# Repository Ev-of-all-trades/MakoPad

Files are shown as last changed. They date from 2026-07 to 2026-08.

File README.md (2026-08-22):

# MakoPad
This is a 6 key macropad that I designed in KiCad and is programmed with QMK. It features a 1.8" LCD display, 6 hot-swappable keys, a rotary encoder, and 2 buttons to switch the layers. This Project has been made specially for programmers on FRC 5199 Robot Dolphins From Outer Space to help them with FRC Programming. 

PCB and Schematic
-----------------------------------------------------



Below is A picture of the assembly I made in Fusion 360.
------------------------------------------------------------------------------------
PCB Assembly [mind the crappy display model, i couldn't find a better one since there wasn't any for the specific one i wanted to use]


Here is the plan for developing the programming
--------------------------------------------------
Phase 1: Keyboard matrix
- Program the keyboard matrix and build the layers
- Test matrix to make sure it works

Phase 2: Rotary encoder
- Add the rotary encoder and rotary encoder switch into the programming
- Program the special functions for the rotary encoder
  - Make it so that whenever the rotary encoder is pressed down, you can rotate the knob to select what function you want to rotary encoder to do
- Test rotation and clicking

Phase 3: Layer buttons
- Program the button to change the keyboard matrix layers
  - The top button switches to the next layer and the bottom one switches to the previous layer

Phase 4: The display
- Make the display interface with the microcontroller

Phase 5: Make it awesome
- Layer-dependent key labels
- Encoder modes
- Custom macros
- Startup screen
- MakoPad logo
- Current layer display
- Key function display

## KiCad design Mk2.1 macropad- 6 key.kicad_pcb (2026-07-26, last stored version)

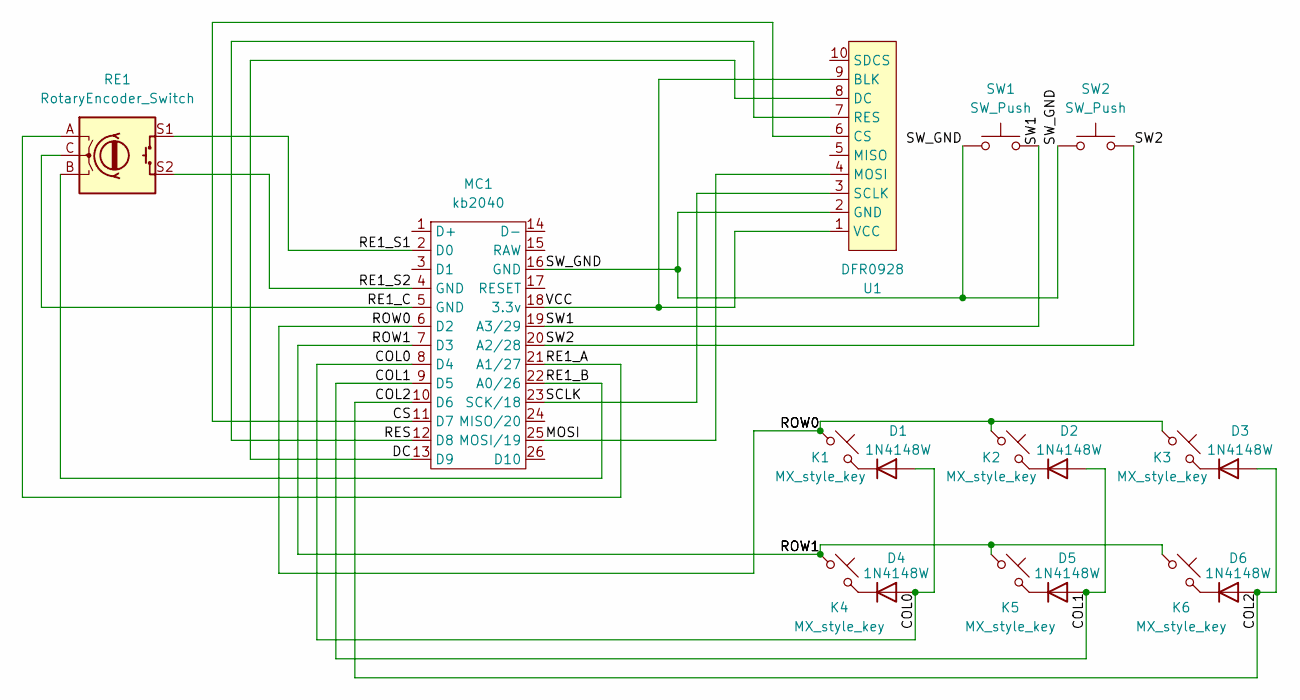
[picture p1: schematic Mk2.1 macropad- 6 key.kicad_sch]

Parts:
D1, D2, D3, D4, D5, D6: 1N4148W; D_SOD-123
K1, K2, K3, K4, K5, K6: MX_style_key; Kailh MX hot-swap socket [part #PG151101S11]
MC1: kb2040
RE1: RotaryEncoder_Switch; RotaryEncoder_Alps_EC11E-Switch_Vertical_H20mm
SW1, SW2: SW_Push; SW_PUSH-12mm
U1: DFR0928; Fermion 1.8in 128x160 IPS TFT LCD Display

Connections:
/COL0: D1.2 (A), D4.2 (A), MC1.8 (D4)
/COL1: D2.2 (A), D5.2 (A), MC1.9 (D5)
/COL2: D3.2 (A), D6.2 (A), MC1.10 (D6)
/CS: MC1.11 (D7), U1.6 (CS)
/DC: MC1.13 (D9), U1.8 (DC)
/MOSI: MC1.25 (MOSI/19), U1.4 (MOSI)
/RE1_A: MC1.21 (A1/27), RE1.A
/RE1_B: MC1.22 (A0/26), RE1.B
/RE1_C: MC1.5 (GND), RE1.C
/RE1_S1: MC1.2 (D0), RE1.S1
/RE1_S2: MC1.4 (GND), RE1.S2
/RES: MC1.12 (D8), U1.7 (RES)
/ROW0: K1.1, K2.1, K3.1, MC1.6 (D2)
/ROW1: K4.1, K5.1, K6.1, MC1.7 (D3)
/SCLK: MC1.23 (SCK/18), U1.3 (SCLK)
/SW1: MC1.19 (A3/29), SW1.2
/SW2: MC1.20 (A2/28), SW2.2
/SW_GND: MC1.16 (GND), SW1.1, SW2.1, U1.2 (GND)
/VCC: MC1.18 (3.3v), U1.1 (VCC), U1.9 (BLK)
unnamed: D1.1 (K), K1.2
unnamed: D2.1 (K), K2.2
unnamed: D3.1 (K), K3.2
unnamed: D4.1 (K), K4.2
unnamed: D5.1 (K), K5.2
unnamed: D6.1 (K), K6.2

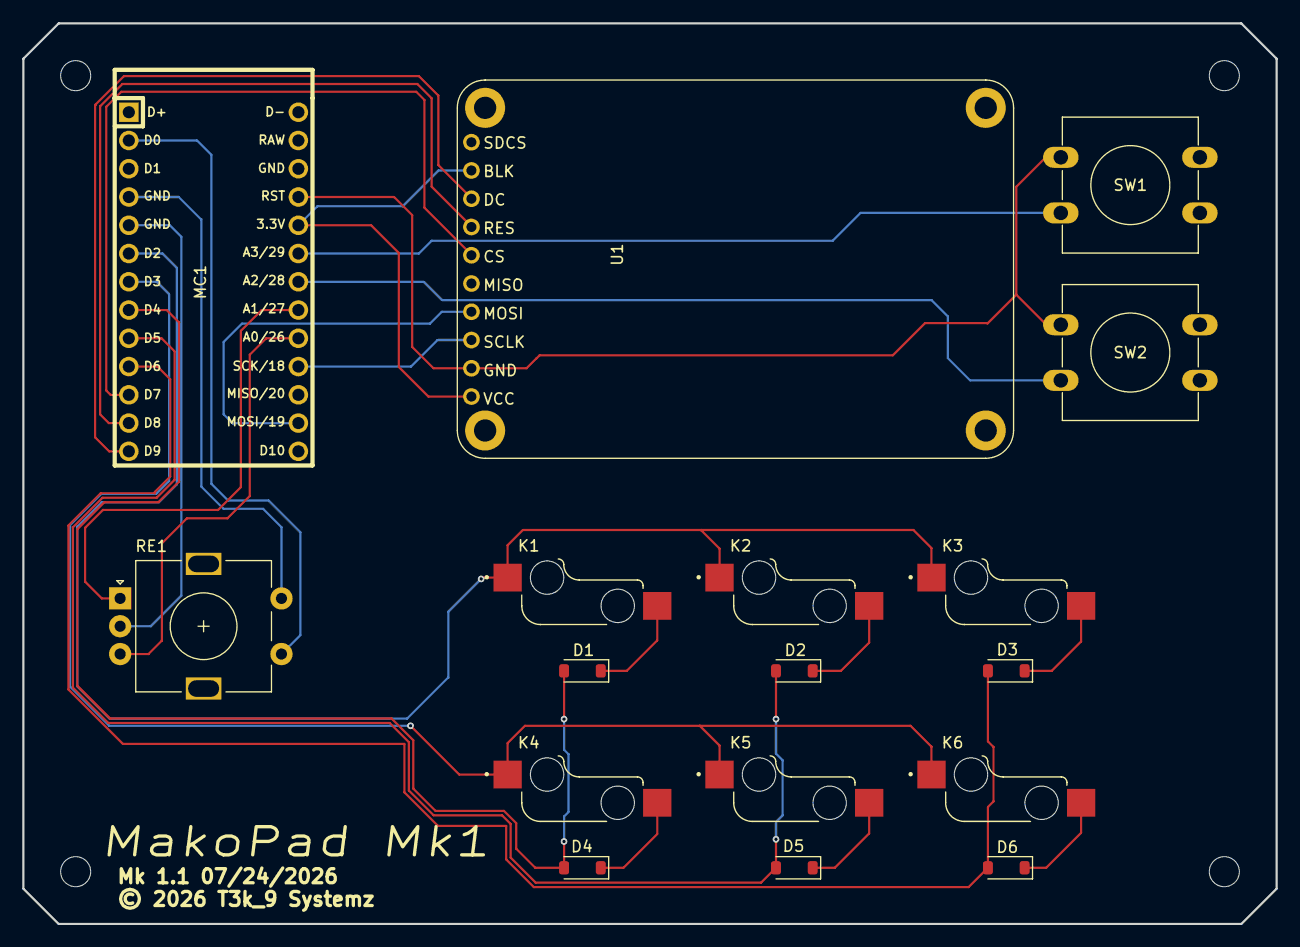
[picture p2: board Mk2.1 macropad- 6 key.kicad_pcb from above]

Board: 2 copper layers, 112.7 x 80.9 mm, 17 parts (0 on the bottom side), 25 nets.

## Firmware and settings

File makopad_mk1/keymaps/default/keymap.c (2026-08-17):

#include QMK_KEYBOARD_H

// ENCODER MODES
typedef enum {
    ENC_VOLUME,
    ENC_SCROLL,
    ENC_BRIGHTNESS
} encoder_mode_t;

static encoder_mode_t encoder_mode = ENC_VOLUME;


// =============================================================================
// LAYERS
// =============================================================================

enum layers {
    _BASE,
    _FRC,
    _DS,
    _LIMELITE,
    _LAYER_COUNT
};


// =============================================================================
// CUSTOM KEYCODES
// =============================================================================

enum custom_keycodes {

    // FRC / VS Code
    FRC_BUILD = SAFE_RANGE,
    FRC_DEPLOY,
    FRC_SIMULATE,
    FRC_DEBUG,
    FRC_RIOLOG,
    FRC_SHUFFLEBOARD,

    // Driver Station
    DS_ENABLE,
    DS_DISABLE,
    DS_TELEOP,
    DS_AUTO,
    DS_TEST,
    DS_ESTOP,
    DS_ASTOP,
    DS_REFRESH,

    // Limelight
    LIMELIGHT_LEFT,
    LIMELIGHT_FRONT,
    LIMELIGHT_RIGHT
};


// =============================================================================
// STANDALONE GPIO PINS
// =============================================================================

#define ENCODER_SW_PIN GP0
#define LAYER_NEXT_PIN GP28
#define LAYER_PREV_PIN GP29


// =============================================================================
// INITIALIZATION
// =============================================================================

void keyboard_post_init_user(void) {

    // Rotary encoder push switch
    setPinInputHigh(ENCODER_SW_PIN);

    // Layer buttons
    setPinInputHigh(LAYER_NEXT_PIN);
    setPinInputHigh(LAYER_PREV_PIN);
}


// =============================================================================
// KEYMAPS
// =============================================================================

const uint16_t PROGMEM keymaps[][MATRIX_ROWS][MATRIX_COLS] = {

    // -------------------------------------------------------------------------
    // BASE LAYER
    // -------------------------------------------------------------------------

    [_BASE] = LAYOUT_ortho_2x3(
        KC_A, KC_B, KC_C,
        KC_D, KC_E, KC_F
    ),


    // -------------------------------------------------------------------------
    // FRC PROGRAMMING
    // -------------------------------------------------------------------------

    [_FRC] = LAYOUT_ortho_2x3(
        FRC_BUILD,
        FRC_DEPLOY,
        FRC_SIMULATE,

        FRC_DEBUG,
        FRC_RIOLOG,
        FRC_SHUFFLEBOARD
    ),


    // -------------------------------------------------------------------------
    // DRIVER STATION
    // -------------------------------------------------------------------------

    [_DS] = LAYOUT_ortho_2x3(
        DS_ENABLE,
        DS_DISABLE,
        DS_TELEOP,

        DS_AUTO,
        DS_TEST,
        DS_ESTOP
    ),


    // -------------------------------------------------------------------------
    // LIMELITE
    // -------------------------------------------------------------------------

    [_LIMELITE] = LAYOUT_ortho_2x3(
        LIMELIGHT_LEFT,
        LIMELIGHT_FRONT,
        LIMELIGHT_RIGHT,

        KC_NO,
        KC_NO,
        KC_NO
    )
};


// =============================================================================
// CUSTOM KEYCODE PROCESSING
// =============================================================================

bool process_record_user(uint16_t keycode, keyrecord_t *record) {

    // Only execute macros when the key is pressed.
    if (!record->event.pressed) {
        return true;
    }

    switch (keycode) {

        // =====================================================================
        // FRC / VS CODE
        // =====================================================================

        case FRC_BUILD:

            // Ctrl + Alt + B
            tap_code16(LCTL(LALT(KC_B)));

            return false;


        case FRC_DEPLOY:

            // Ctrl + Alt + D
            tap_code16(LCTL(LALT(KC_D)));

            return false;


        case FRC_SIMULATE:

            // Ctrl + Alt + S
            tap_code16(LCTL(LALT(KC_S)));

            return false;


        case FRC_DEBUG:

            // Ctrl + Alt + G
            tap_code16(LCTL(LALT(KC_G)));

            return false;


        case FRC_RIOLOG:

            // Ctrl + Alt + R
            tap_code16(LCTL(LALT(KC_R)));

            return false;


        case FRC_SHUFFLEBOARD:

            // Ctrl + Alt + M
            tap_code16(LCTL(LALT(KC_M)));

            return false;


        // =====================================================================
        // DRIVER STATION
        // =====================================================================

        case DS_ENABLE:

            // Driver Station native enable shortcut:
            // [ + ] + \ 
            tap_code(KC_LBRC);
            tap_code(KC_RBRC);
            tap_code(KC_BSLS);

            return false;


        case DS_DISABLE:
            // Enter
            tap_code(KC_ENT);

            return false;


        case DS_TELEOP:
            // Ctrl + Alt + T
            tap_code16(LCTL(LALT(KC_T)));

            return false;


        case DS_AUTO:
            // Ctrl + Alt + A
            tap_code16(LCTL(LALT(KC_A)));

            return false;


        case DS_TEST:
            // Ctrl + Alt + S
            tap_code16(LCTL(LALT(KC_S)));

            return false;


        case DS_ESTOP:
            // Space
            tap_code(KC_SPC);

            return false;


        case DS_ASTOP:
            // Backspace
            tap_code(KC_BSPC);

            return false;


        case DS_REFRESH:
            // F1
            tap_code(KC_F1);

            return false;


        // =====================================================================
        // LIMELITE
        // =====================================================================

        case LIMELIGHT_LEFT:

            SEND_STRING("10.51.99.11:5801");

            return false;


        case LIMELIGHT_FRONT:

            SEND_STRING("10.51.99.12:5801");

            return false;


        case LIMELIGHT_RIGHT:

            SEND_STRING("10.51.99.13:5801");

            return false;
    }

    return true;
}


// =============================================================================
// ROTARY ENCODER
// =============================================================================
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

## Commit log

2026-07-26 Update README.md
    Added details about features and included images of the PCB and schematic.
2026-07-26 KiCad 10.0 Files Uploaded. Programming comes later
    [Mk2.1 macropad- 6 key.kicad_pcb, Mk2.1 macropad- 6 key.kicad_sch]
2026-07-26 KiCad Files swapped with gerbers
    [Mk2.1 macropad- 6 key.kicad_sch]
2026-07-26 Add images to README for PCB and schematic
    Added additional images of the PCB and schematic to the README.
2026-07-28 Enhance README with assembly images and descriptions
    Added images and descriptions of assemblies made in Fusion 360.
2026-08-04 Deleted old Gerbers
    [MakoPad Mk1-B_Cu.gbl, MakoPad Mk1-B_Mask.gbs, MakoPad Mk1-B_Paste.gbp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]
2026-08-04 new gerber files
    [MakoPad Mk1-B_Cu.gbl, MakoPad Mk1-B_Mask.gbs, MakoPad Mk1-B_Paste.gbp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]
2026-08-04 Replace PCB image in README
    Updated image links in the README to reflect new assets.
2026-08-04 Update image link in README.md
    Updated the image link in the PCB and Schematic section.
2026-08-08 Revise PCB Assembly description in README
    Updated the PCB Assembly section with a note about the screen model used.
2026-08-10 Replace PCB images in README
    Updated images in the PCB and Schematic section of the README.
2026-08-14 Replace PCB assembly image in README
    Updated image in README.md to a better representation of the PCB assembly.
2026-08-22 Fix typo in PCB Assembly description
    Corrected a typo in the PCB Assembly description.

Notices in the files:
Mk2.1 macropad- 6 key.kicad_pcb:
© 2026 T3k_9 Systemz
